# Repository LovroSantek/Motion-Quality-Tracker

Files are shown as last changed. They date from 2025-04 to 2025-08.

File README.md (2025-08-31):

# Motion Quality Tracker

**Author**: Lovro Šantek, May 2025.

## Overview

**Motion Quality Tracker** is a wearable system designed to provide **real-time feedback** on exercise performance using motion analysis. It aims to help users perform exercises with correct form, minimizing injury risks and maximizing training efficiency. The solution leverages embedded AI for instant evaluation of movement quality.

🎥 [YouTube demo ](https://youtu.be/wWR3Q_hF_YM)(Croatian)

---

## Problem Statement

Incorrect exercise technique is a widespread issue affecting:
- Beginners: leading to poor results.
- Experienced athletes: risking injuries and imbalances.
- Rehabilitation patients: struggling with proper guidance.

Traditional supervision is costly and time-consuming. There’s a need for **independent, intelligent feedback systems**.

---

## Solution

A compact wearable device that includes:
- **IMU sensor**: Collects movement data (acceleration + angular velocity).
- **ESP32 microcontroller**: Processes sensor data and runs on-device AI inference.
- **AI Model (TensorFlow Lite / LiteRT)**: Classifies motion patterns.
- **Wireless communication**: Integration with a web app.
- **3D printed case**: Lightweight and body-attachable.
- **Battery-powered (Li-ion + USB-C charging)**.

---

## Hardware Components

| Component | Quantity | Price | Link |
|---|---|---|---|
| ESP32-DevKit V1 | 1 | €9.50 | [Mouser](https://www.mouser.de/ProductDetail/Espressif-Systems/ESP32-DevKitC-VIE) |
| Li-ion battery (900mAh) | 1 | €6.95 | [Soldered](https://soldered.com/product/li-ion-battery-900mah-3-7v/) |
| BQ24295 Charger | 1 | €12.50 | [Soldered](https://soldered.com/product/li-ion-charger-bq24295-with-5v-usb-output-board/) |
| IMU Sensor | 1 | €17.10 | [Mouser](https://www.mouser.de/ProductDetail/Mikroe/MIKROE-4044) |
| PLA Filament | 1 | €22.99 | [BambuLab](https://eu.store.bambulab.com/de/collections/pla/products/pla-basic-filament-de) |

**Total Cost**: €69.04

---

## System Architecture

- **Sensor**: IMU (Accelerometer + Gyroscope) via SPI
- **Controller**: ESP32 (Wi-Fi/MQTT)
- **Power**: Li-ion battery + BQ24295 charger
- **Software**: EdgeImpulse for data collection, LiteRT for inference
- **App**: Mobile/Web integration for feedback display

---

## Software Design

Structured in modular layers:

1. **Hardware Abstraction Layer (HAL)** – SPI interface, power management  
2. **Data Acquisition Module** – Gathers IMU data  
3. **AI Inference Module** – Real-time classification using LiteRT  
4. **Communication Module** – MQTT data transmission  

**Flowchart:**
1. Initialize System  
2. Acquire IMU Data  
3. Run AI Inference  
4. Send Output to an App

---
### Feedback Screens WebPage

Below are examples of how the user interface provides feedback based on exercise quality.

<p align="center">
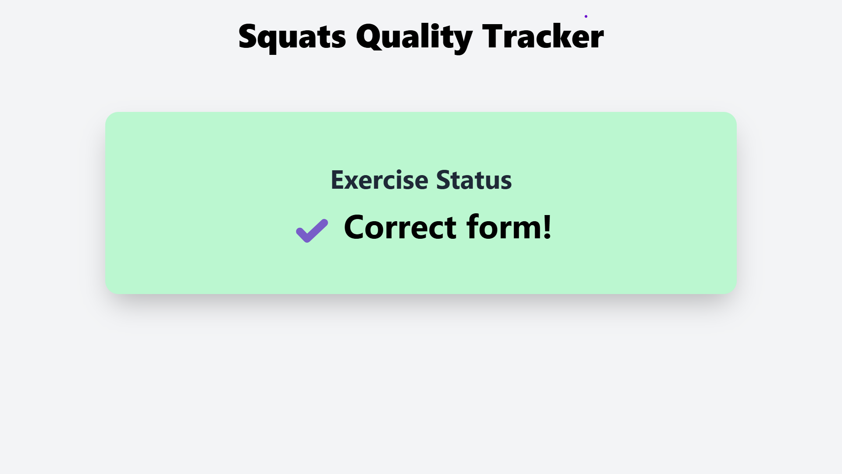
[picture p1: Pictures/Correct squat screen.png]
Correct Exercise
  
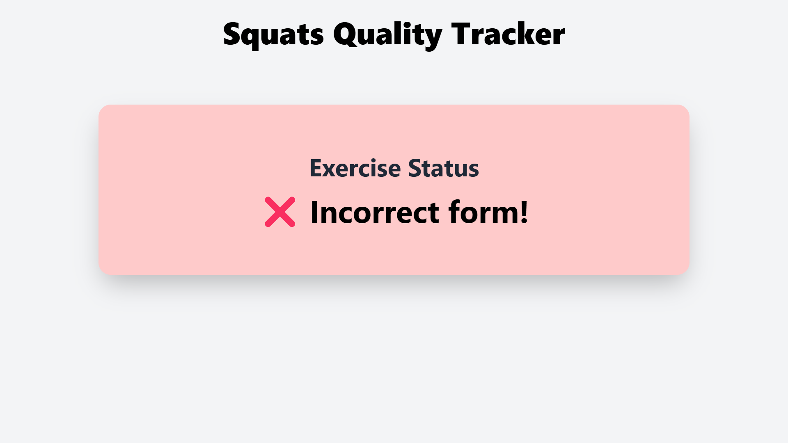
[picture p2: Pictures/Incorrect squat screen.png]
Incorrect Exercise
  
</p>

<p align="center">
  <em>Left: Proper squat form detected and confirmed • Right: User performed a squat with incorrect form </em>
</p>

---

## Links

- [EdgeImpulse Studio private project](https://studio.edgeimpulse.com/studio/684917)
- [Repo with MQTT setup instructions](https://github.com/LovroSantek/MQTT-webpage-example)

---

## Enclosure

Custom 3D printed case to house all components and mount on the body safely and comfortably.
The case was modeled in [Fusion360](https://www.autodesk.com/products/fusion-360).

<p align="center">
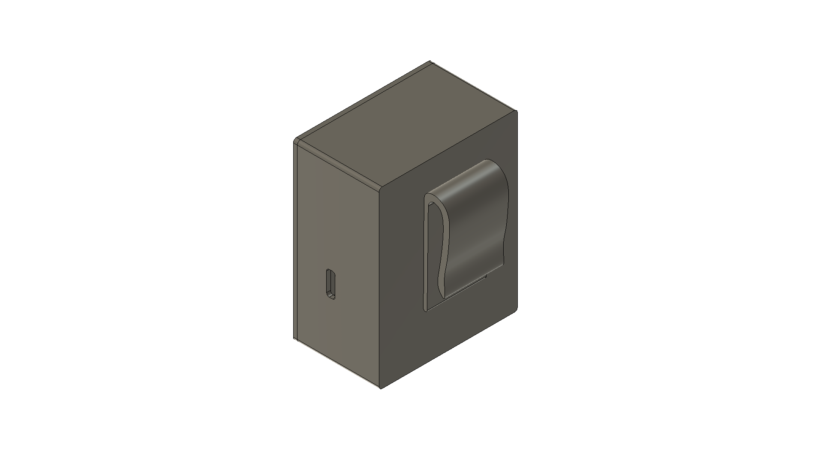
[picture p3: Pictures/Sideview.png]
Side view
  
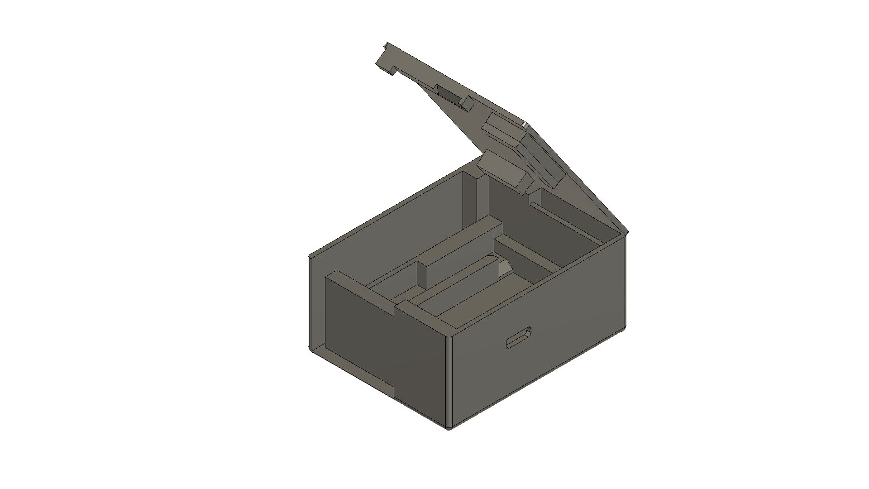
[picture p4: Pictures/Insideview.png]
Inside view
  
</p>

---

## Acknowledgements

Thanks to everyone who participated in data collection for model training.

---

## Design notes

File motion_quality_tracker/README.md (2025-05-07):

# Firmware – Motion Quality Tracker

This folder contains the **firmware source code** for the Motion Quality Tracker project. The firmware runs on the ESP32-WROVER and handles IMU data collection, on-device AI inference, and MQTT communication with the feedback web app.

---

## Overview

The firmware workflow is built around four key modules:

1. **IMU Driver (`IMU_driver.c/h`)**  
   Interfaces with the motion sensor over SPI to collect acceleration and gyroscopic data.

2. **AI Inference (Edge Impulse SDK)**  
   Runs a TensorFlow Lite model using the `edge-impulse-sdk/` directory, classifying squats in real time.

3. **MQTT Module (`mqtt_module.c/h`)**  
   Connects to a local MQTT broker over Wi-Fi and publishes feedback results (e.g., `Correct Squat`, `Incorrect Squat`).

4. **Main Logic (`main.cpp`)**  
   - Initializes all modules  
   - Loops: collects features → classifies → sends results via MQTT

---

## File Structure

```bash
main/
├── inc/                  # Header files
│   ├── IMU_driver.h
│   └── mqtt_module.h
├── src/                  # Source files
│   ├── IMU_driver.c
│   └── mqtt_module.c
├── main.cpp              # Application entry point (app_main)
├── CMakeLists.txt        # Component build config
```
---

## Build & Flash Instructions (ESP-IDF)

Before building, make sure you have [ESP-IDF installed](https://docs.espressif.com/projects/esp-idf/en/latest/esp32/get-started/index.html) and sourced in your terminal.

---

### 1. Configure Wi-Fi and MQTT Settings

Before building the project, you must **set your Wi-Fi network credentials** and **MQTT broker IP address** in `main.cpp`:

```cpp
#define WIFI_SSID "YourWiFiName"
#define WIFI_PASS "YourWiFiPassword"
#define MQTT_BROKER_URI "mqtt://192.168.x.x:1883"
````

Detailed setup instructions can be found in this repository: [MQTT-webpage-example – GitHub](https://github.com/LovroSantek/MQTT-webpage-example)

---

### 2. Build and Flash the Firmware

From the root of your project (where `main/` is located), run:

```bash
idf.py set-target esp32
idf.py build
idf.py -p /dev/ttyUSB0 flash monitor
```

* Replace `/dev/ttyUSB0` with the actual port your ESP32 is connected to (check with `ls /dev/tty.*` on macOS or `Device Manager` on Windows).
* Use `idf.py monitor` to view real-time logs after flashing.

---

### Notes

* The firmware connects to your Wi-Fi and starts publishing classification results to the MQTT broker.
* You can verify message reception using the companion web app above.
* Ensure your MQTT broker is running and accessible from the ESP32 (i.e., same local network).

---
---

### Running Wirelessly

Once the firmware is flashed and the system is verified to be working over USB:

- Disconnect the ESP32 from your computer
- Connect a charged Li-ion battery (e.g. 3.7V 900mAh) via the BQ24295 charger board
- The device will automatically boot and connect to Wi-Fi

**When everything works, the ESP32 can be powered by battery and is fully ready for standalone wireless use**  
No computer connection is required after initial flashing.

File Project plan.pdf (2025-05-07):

Problem statement and solution overview | April 2025

# Motion Quality Tracker

Contestant Lovro Santek ˇ

## Problem statement

Physical activity is widely encouraged as a key to a healthy lifestyle, but what is even more important than exercise itself, is to do it correctly. Inappropriate exercise technique is a widespread problem that affects people of all levels of fitness and all sports, as stated in this study. (https://pmc.ncbi.nlm.nih.gov/articles/PMC5005555/) For beginners, it often leads to suboptimal results, while for more experienced individuals, it can contribute to joint strain, muscle imbalances, or even long-term injuries. In rehabilitation settings, patients may struggle to perform movements correctly due to lack of proper guidance.
In addition, learning a new exercise or sport often requires continuous supervision from a qualified expert. This dependence on another person not only increases the cost but also consumes valuable time for both the user and the trainer. As a result, it limits the potential for effective and independent training.

## Solution overview

The proposed solution is a wearable system that provides real-time feedback on exercise performance, using motion analysis to detect and correct improper technique.
Each exercise has characteristic movement patterns that define whether it is performed correctly. For example, an incorrectly executed squat can lead to knee or lower back injuries. A properly performed squat typically includes a straight back, correct foot positioning, adequate depth, and balanced weight distribution. Since the human body moves during the squat, an IMU sensor placed on the pants at hip level can collect relevant motion data. This sensor provides measurements of acceleration and angular velocity, which can be analyzed to determine whether the movement matches the expected correct form.
Depending on the exercise, the device can be positioned elsewhere on the body, provided that the chosen location offers sufficient data for performance evaluation and does not obstruct users movement. The systems requires a few key building blocks.
- IMU sensor
- ESP32 microcontroller
- AI model
- Custom 3D printed enclosure
IMU Sensor | ESP32 | Battery

Web/Mobile App

SPI | 3.3 V

Wi-Fi/BLE

Figure 1: System architecture.

The IMU sensor combines MEMS accelerometer and gyroscope to collect motion data (acceleration and angular velocity), which is transferred to the microcontroller via SPI. The selected microcontroller is the ESP32, chosen for its wireless communication capabilities (Wi-Fi/Bluetooth). It enables integration with a mobile or web application that displays the exercise feedback. ESP32 is battery-powered to enable easy attachment to the body and ensure unrestricted body movement. A Li-ion battery and the BQ24295 charger with built-in protection will be used. The device will be rechargeable via a USB-C charger, ensuring convenient and efficient charging.
The AI model will be trained using a manually collected dataset¹ of accelerometer and gyroscope signals, utilizing the LiteRT (TensorFlow Lite) framework. The EdgeImpulse (https://studio.edgeimpulse.com/) platform will be used for data acquisition. The AI model will be deployed directly on the microcontroller, ensuring low latency and real-time classification with a target accuracy above 90 %. This approach follows the Edge AI paradigm, where inference is performed locally on the embedded device, eliminating the need for cloud connectivity and enabling on-device decision-making.
All hardware components will be integrated into a compact 3D-printed enclosure suitable for body attachment.

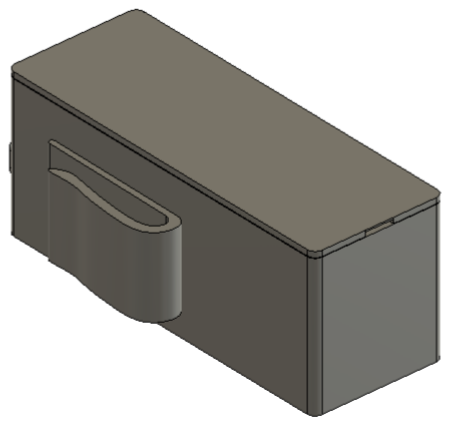
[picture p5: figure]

Figure 2: Proposed wearable enclosure for hardware components.

## Software design

The software architecture is designed with a modular and layered approach to ensure clarity and scalability. At the lowest level, the Hardware Abstraction Layer (HAL) interfaces directly with the IMU sensor using the SPI protocol and manages power-related functions. A dedicated Data Acquisition module continuously gathers accelerometer and gyroscope signals for further analysis.
The core of the system lies in the AI Inference module, which runs a lightweight model optimized using LiteRT. (https://ai.google.dev/edge/litert) This model classifies motion patterns in real time with minimal latency. Above this, a Communication module handles wireless data transmission over Wi-Fi or Bluetooth Low Energy (BLE), allowing the device to interface with a web or mobile application. All tasks are managed by a FreeRTOS. (https://www.freertos.org/)

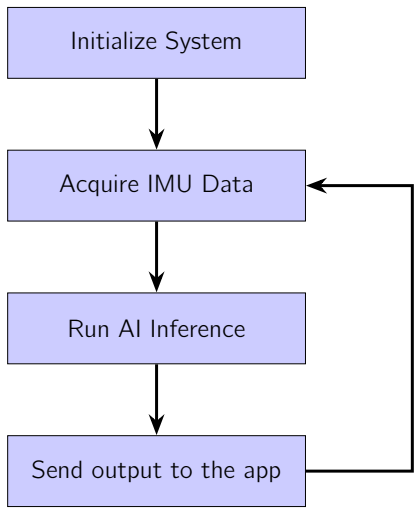
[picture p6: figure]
Initialize System; Acquire IMU Data; Run AI Inference; Send output to the app

Figure 3: Flow diagram of the Motion Quality Tracker system.

1The training and validation data will be collected from various colleagues at the university.

## List of hardware components and budget estimation

Component | Quantity | Price | Link to product
ESP32-DevKit V1 | 1 | 9,50 € | Mouser (https://www.mouser.de/ProductDetail/Espressif-Systems/ESP32-DevKitC-VIE)
Li-ion battery 900mAh, 3,7V | 1 | 6,95 € | Soldered (https://soldered.com/product/li-ion-battery-900mah-3-7v/)
Li-ion charger BQ24295 | 1 | 12,50 € | Soldered (https://soldered.com/product/li-ion-charger-bq24295-with-5v-usb-output-board/)
IMU Sensor | 1 | 17,10 € | Mouser (https://www.mouser.de/ProductDetail/Mikroe/MIKROE-4044?qs=GedFDFLaBXEoRuvP6SWIxw%3D%3D)
PLA Filament | 1 | 22,99 € | BambuLab (https://eu.store.bambulab.com/de/collections/pla/products/pla-basic-filament-de?variant=42911328075995)

Total price: 69,04 €

Table 1: Components and budget overview.

## Validation of the final product

Once the project is complete, it is essential to ensure that it functions correctly. For the Motion Quality Tracker device, this primarily involves evaluating the accuracy of the AI model running on the microcontroller. The accuracy will be tested by selecting a specific exercise, such as a squat, and gathering data from various individuals. Some of these individuals will perform the exercise correctly, while others will perform it incorrectly. The device’s ability to correctly identify proper versus improper form will be tracked, and its accuracy will be calculated based on these results.
Additionally, the device can be used to validate a variety of movements beyond squats, such as a tennis racket swing or a soccer ball kick. By testing these different exercises, it will be possible to assess where the device performs most accurately and determine its most suitable applications.

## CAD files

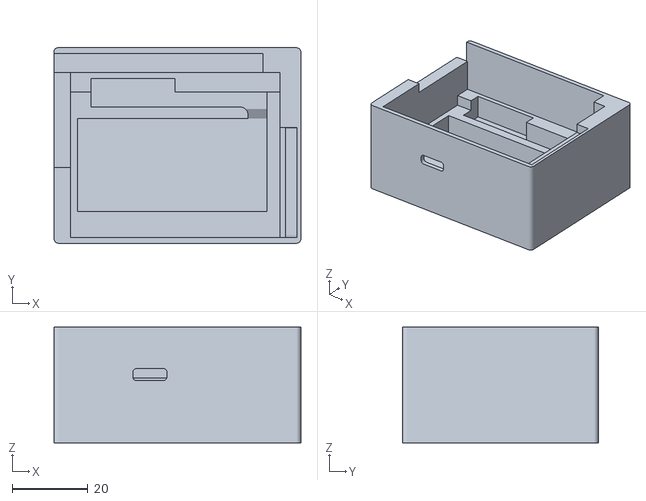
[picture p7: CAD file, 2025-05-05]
3D models/Case - Motion Quality Tracker.stl
65.1 x 51.6 x 30.5

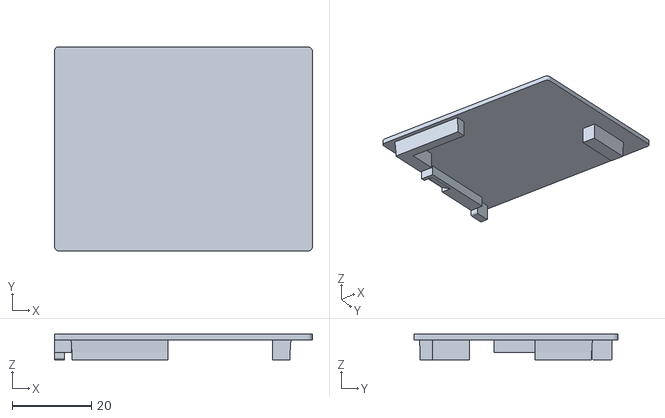
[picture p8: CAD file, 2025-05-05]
3D models/Cap - Motion Quality Tracker.stl
65.1 x 51.6 x 6.50

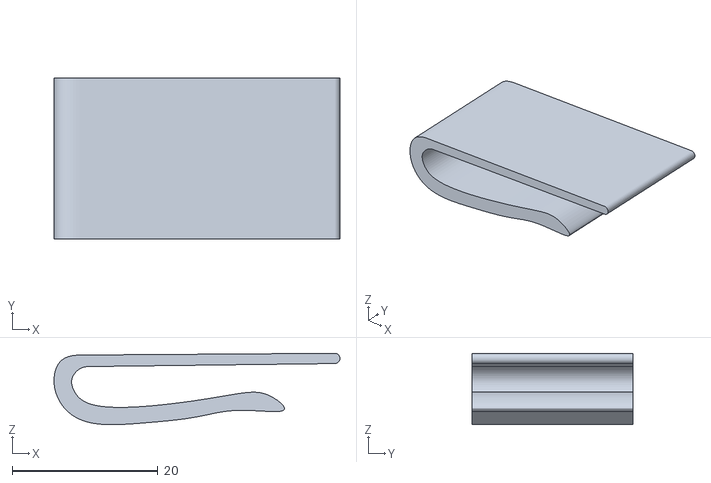
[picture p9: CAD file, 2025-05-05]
3D models/Clip - Motion Quality Tracker.stl
39.2 x 22.0 x 9.78

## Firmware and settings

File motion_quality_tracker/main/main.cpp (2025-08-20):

/* Edge Impulse Espressif ESP32 Standalone Inference ESP IDF Example
 * Copyright (c) 2022 EdgeImpulse Inc.
 *
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
 * THE SOFTWARE IS PROVIDED "AS IS", WITHOUT WARRANTY OF ANY KIND, EXPRESS OR
 * IMPLIED, INCLUDING BUT NOT LIMITED TO THE WARRANTIES OF MERCHANTABILITY,
 * FITNESS FOR A PARTICULAR PURPOSE AND NONINFRINGEMENT. IN NO EVENT SHALL THE
 * AUTHORS OR COPYRIGHT HOLDERS BE LIABLE FOR ANY CLAIM, DAMAGES OR OTHER
 * LIABILITY, WHETHER IN AN ACTION OF CONTRACT, TORT OR OTHERWISE, ARISING FROM,
 * OUT OF OR IN CONNECTION WITH THE SOFTWARE OR THE USE OR OTHER DEALINGS IN THE
 * SOFTWARE.
 */

/* Include ----------------------------------------------------------------- */
#include <stdio.h>
#include "IMU_driver.h"
#include "mqtt_module.h"

#include "edge-impulse-sdk/classifier/ei_run_classifier.h"

/* Adjust based on the Wi-Fi the computer is connected to.*/
//--------------------------------------------------------
#define WIFI_SSID "Santek"
#define WIFI_PASS "51903586768881504177"
#define MQTT_BROKER_URI "mqtt://192.168.1.187:1883"
//--------------------------------------------------------

#define DECISION_THRESHOLD (0.45f)

int raw_feature_get_data(size_t offset, size_t length, float *out_ptr) {
    for(int i = 0; i < EI_CLASSIFIER_RAW_SAMPLE_COUNT; i++)
    {
        float ax = IMU_read_accel(ACCEL_XOUT_H);
        //float ay = IMU_read_accel(ACCEL_YOUT_H); //  Not used for this model
        float az = IMU_read_accel(ACCEL_ZOUT_H);

        float gx = IMU_read_gyro(GYRO_XOUT_H);
        float gy = IMU_read_gyro(GYRO_YOUT_H);
        //float gz = IMU_read_gyro(GYRO_ZOUT_H); //  Not used for this model

        out_ptr[EI_CLASSIFIER_RAW_SAMPLES_PER_FRAME * i + 0] = ax;
        out_ptr[EI_CLASSIFIER_RAW_SAMPLES_PER_FRAME * i + 1] = az;
        out_ptr[EI_CLASSIFIER_RAW_SAMPLES_PER_FRAME * i + 2] = gx;
        out_ptr[EI_CLASSIFIER_RAW_SAMPLES_PER_FRAME * i + 3] = gy;

        ei_sleep((int)(1000 / EI_CLASSIFIER_FREQUENCY));
    }

    return 0;
}

void print_inference_result(ei_impulse_result_t result) {

    // Print how long it took to perform inference
    
    ei_printf("Timing: DSP %d ms, inference %d ms, anomaly %d ms\r\n",
            result.timing.dsp,
            result.timing.classification,
            result.timing.anomaly);
    

    ei_printf("Predictions:\r\n");
    for (uint16_t i = 0; i < EI_CLASSIFIER_LABEL_COUNT; i++)
    {
        ei_printf("  %s: ", ei_classifier_inferencing_categories[i]);
        ei_printf("%.5f\r\n", result.classification[i].value);
        if(result.classification[i].value > DECISION_THRESHOLD)
        {
            mqtt_publish_exercise_result(ei_classifier_inferencing_categories[i]);
        }
    }

    // Print anomaly result (if it exists)
#if EI_CLASSIFIER_HAS_ANOMALY == 1
    ei_printf("Anomaly prediction: %.3f\r\n", result.anomaly);
#endif

}

extern "C" int app_main()
{
    IMU_init();
    ei_sleep(100);
    wifi_init_and_start_mqtt(WIFI_SSID, WIFI_PASS, MQTT_BROKER_URI);
    ei_sleep(2000);

    ei_impulse_result_t result = {nullptr};

    ei_printf("Application started!\n");

    while (true)
    {
        signal_t features_signal;
        features_signal.total_length = EI_CLASSIFIER_DSP_INPUT_FRAME_SIZE;
        features_signal.get_data = &raw_feature_get_data;

        // invoke the impulse
        EI_IMPULSE_ERROR res = run_classifier(&features_signal, &result, false /* debug */);
        if (res != EI_IMPULSE_OK) {
            ei_printf("ERR: Failed to run classifier (%d)\n", res);
            return res;
        }

        print_inference_result(result);
    }
}

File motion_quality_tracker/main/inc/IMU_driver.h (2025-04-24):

#ifndef IMU_DRIVER_H
#define IMU_DRIVER_H

#include <string.h>
#include "driver/spi_master.h"
#include "esp_log.h"

// Pin definitions for SPI
#define PIN_NUM_MISO 19
#define PIN_NUM_MOSI 23
#define PIN_NUM_CLK 18
#define PIN_NUM_CS 5

#define MAX_TRANSFER_SIZE 512
#define SPI_WRITE_MASK 0X7F
#define SPI_READ_MASK 0X80
 
#define USER_BANK_REG_ADDRESS 0X7F
#define PWR_MGMT_REG_ADDRESS 0X06
#define WAKE_UP_MASK 0X01
#define SLEEP_MASK 0X41

// Accelerometer result registers
#define ACCEL_XOUT_H 0x2D
#define ACCEL_YOUT_H 0X2F
#define ACCEL_ZOUT_H 0X31

// Gyroscope result registers
#define GYRO_XOUT_H 0X33
#define GYRO_YOUT_H 0X35
#define GYRO_ZOUT_H 0X37

#define ACCEL_SENSITIVITY 16384.0  // Sensitivity setting for the accelerometer (+-2g option)
#define GYRO_SENSITIVITY 131.0  // Sensitivity setting for the gyroscope ()

extern spi_device_handle_t spi_handle;  // Declaration of the SPI device handle

#ifdef __cplusplus
extern "C" {
#endif

typedef enum {
    IMU_SUCCESS = 1,        // Success
    IMU_INIT_SUCCESS = 0,   // Initialization success
    IMU_ERROR = -1,         // Error
} IMU_status_t;

/**
 * @brief Initializes the IMU sensor and SPI communication.
 *
 * This function configures the SPI bus and adds the IMU device to it. 
 * It also wakes up the sensor by writing to the power management register.
 *
 * @return IMU_status_t Returns IMU_INIT_SUCCESS if initialization is successful, otherwise IMU_ERROR.
 */

IMU_status_t IMU_init();

/**
 * @brief Reads a register from the sensor via SPI.
 *
 * This function sends a read command to the specified register address
 * and retrieves the corresponding value from the sensor.
 *
 * @param address The address of the register to read.
 * @return uint8_t The value read from the register.
 */
uint8_t read_register(uint8_t address);

/**
 * @brief Writes a value to a register on the sensor via SPI.
 *
 * @param address The address of the register to write to.
 * @param value The value to write.
 * @return IMU_status_t Returns IMU_SUCCESS if the operation was successful, otherwise IMU_ERROR.
 */
IMU_status_t write_register(uint8_t address, uint8_t value);

/**
 * @brief Reads the accelerometer value from a given register address.
 *
 * @param accel_out_address The address of the accelerometer output register.
 * @return float The acceleration value in g units.
 */
float IMU_read_accel(uint8_t accel_out_address);

/**
 * @brief Reads the gyroscope value from a given register address.
 *
 * @param gyro_out_address The address of the gyroscope output register.
 * @return float The angular velocity in degrees per second (dps).
 */
float IMU_read_gyro(uint8_t gyro_out_address);

#ifdef __cplusplus
}
#endif

#endif

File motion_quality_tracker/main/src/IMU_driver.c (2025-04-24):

#include "IMU_driver.h"

spi_device_handle_t spi_handle;

IMU_status_t IMU_init()
{
    spi_bus_config_t buscfg = {};
    buscfg.mosi_io_num = PIN_NUM_MOSI;
    buscfg.miso_io_num = PIN_NUM_MISO;
    buscfg.sclk_io_num = PIN_NUM_CLK;
    buscfg.quadwp_io_num = -1;
    buscfg.quadhd_io_num = -1;
    buscfg.max_transfer_sz = MAX_TRANSFER_SIZE;

    esp_err_t result = spi_bus_initialize(VSPI_HOST, &buscfg, SPI_DMA_CH_AUTO);
    if (result != ESP_OK)
    {
        ESP_LOGE("SPI", "Failed to initialize bus: %s", esp_err_to_name(result));
        return IMU_ERROR;
    }

    spi_device_interface_config_t devcfg = {};
    devcfg.clock_speed_hz = 1000000;  // Clock 1 MHz
    devcfg.mode = 0;  // SPI mode 0
    devcfg.spics_io_num = PIN_NUM_CS;
    devcfg.queue_size = 1;

    result = spi_bus_add_device(VSPI_HOST, &devcfg, &spi_handle);
    if (result != ESP_OK)
    {
        ESP_LOGE("SPI", "Failed to setup SPI: %s", esp_err_to_name(result));
        spi_bus_free(VSPI_HOST);
        return IMU_ERROR;
    }
    else
    {
        ESP_LOGI("SPI", "SPI setup successful");
    }

    if (write_register(PWR_MGMT_REG_ADDRESS, WAKE_UP_MASK) == IMU_SUCCESS)
    {
        ESP_LOGI("SPI: ", "Sensor is no longer in sleep mode");
        return IMU_INIT_SUCCESS;
    }
    else
    {
        return IMU_ERROR;
    }
}

uint8_t read_register(uint8_t address)
{
    uint8_t send_buf[2] = {(uint8_t)(SPI_READ_MASK | address), (uint8_t)0x00};
    uint8_t recv_buf[2] = {0};

    spi_transaction_t t = {};
    t.length = 16;             // Total bits to transfer
    t.tx_buffer = send_buf;    // Transmit buffer
    t.rx_buffer = recv_buf;    // Receive buffer

    esp_err_t ret = spi_device_transmit(spi_handle, &t);
    if (ret != ESP_OK) {
        ESP_LOGE("SPI", "Failed to transmit: %s", esp_err_to_name(ret));
    } else {
        ESP_LOGI("SPI", "Received: 0x%02X", recv_buf[1]);
    }

return recv_buf[1];

}

IMU_status_t write_register(uint8_t address, uint8_t value)
{
    uint8_t tx_data[2];
    tx_data[0] = address & 0x7F;  // Postavljamo MSB na 0 za pisanje
    tx_data[1] = value;

    spi_transaction_t transaction = {
        .length = 16,  // 2 bajta = 16 bitova
        .tx_buffer = tx_data,
        .rx_buffer = NULL,
    };

    esp_err_t result = spi_device_transmit(spi_handle, &transaction);
    if (result != ESP_OK)
    {
        ESP_LOGE("SPI", "Failed to write to sensor: %s", esp_err_to_name(result));
        return IMU_ERROR;
    }
    else
    {
        ESP_LOGI("SPI", "Data 0x%X written to register 0x%X successfully", value, address);
        return IMU_SUCCESS;
    }
}

float IMU_read_accel(uint8_t accel_out_address)
{
    uint8_t tx_data_high[2] = {(uint8_t)(SPI_READ_MASK | accel_out_address), (uint8_t)0x00};
    uint8_t rx_data_high[2] = {0};
    
    spi_transaction_t trans_high = {};
    trans_high.length = 16;
    trans_high.tx_buffer = tx_data_high;
    trans_high.rx_buffer = rx_data_high;
    spi_device_transmit(spi_handle, &trans_high);

    uint8_t tx_data_low[2] = {(uint8_t)(SPI_READ_MASK | (accel_out_address + 1)), (uint8_t)0x00};
    uint8_t rx_data_low[2] = {0};

    spi_transaction_t trans_low = {};
    trans_low.length = 16;
    trans_low.tx_buffer = tx_data_low;
    trans_low.rx_buffer = rx_data_low;
    spi_device_transmit(spi_handle, &trans_low);

    int16_t accel = ((int16_t)rx_data_high[1] << 8) | rx_data_low[1];

    return accel / ACCEL_SENSITIVITY;
}

float IMU_read_gyro(uint8_t gyro_out_address)
{
    uint8_t tx_data_high[2] = {(uint8_t)(SPI_READ_MASK | gyro_out_address), (uint8_t)0x00};
    uint8_t rx_data_high[2] = {0};
    
    spi_transaction_t trans_high = {};
    trans_high.length = 16;
    trans_high.tx_buffer = tx_data_high;
    trans_high.rx_buffer = rx_data_high;
    spi_device_transmit(spi_handle, &trans_high);

    uint8_t tx_data_low[2] = {(uint8_t)(SPI_READ_MASK | (gyro_out_address + 1)), (uint8_t)0x00};
    uint8_t rx_data_low[2] = {0};

    spi_transaction_t trans_low = {};
    trans_low.length = 16;
    trans_low.tx_buffer = tx_data_low;
    trans_low.rx_buffer = rx_data_low;
    spi_device_transmit(spi_handle, &trans_low);

    int16_t gyro_raw = ((int16_t)rx_data_high[1] << 8) | rx_data_low[1];

    return gyro_raw / GYRO_SENSITIVITY;
}

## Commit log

2025-04-23 Initial commit, sample project.
2025-04-24 Test for wireless part.
2025-04-24 Add IMU driver.
2025-05-05 Add case 3D models.
    [Cap - Motion Quality Tracker.stl, Case - Motion Quality Tracker.stl, Clip - Motion Quality Tracker.stl]
